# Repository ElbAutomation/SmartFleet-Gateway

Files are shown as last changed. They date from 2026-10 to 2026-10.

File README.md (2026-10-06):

# SmartFleet Gateway

Mehr zu SmartFleet: <https://smartfleetmanager.de> · Handbuch:
<https://smartfleetmanager.de/docs/>

Das SmartFleet Gateway ist ein Hutschienengerät mit 2 TE für den
Schaltschrank. Es verbindet einen Loxone Miniserver vor Ort mit dem
SmartFleet-Server des Loxone-Partners: Einrichtung über ein eigenes WLAN,
danach Kopplung und Datenaustausch über LAN oder WLAN.

*English: DIN-rail gateway (2 modules) that connects a Loxone Miniserver to a
SmartFleet server. This repository holds the firmware image and the carrier
board (Fritzing project, schematic, Gerber files, bill of materials and build
guide, in German).*

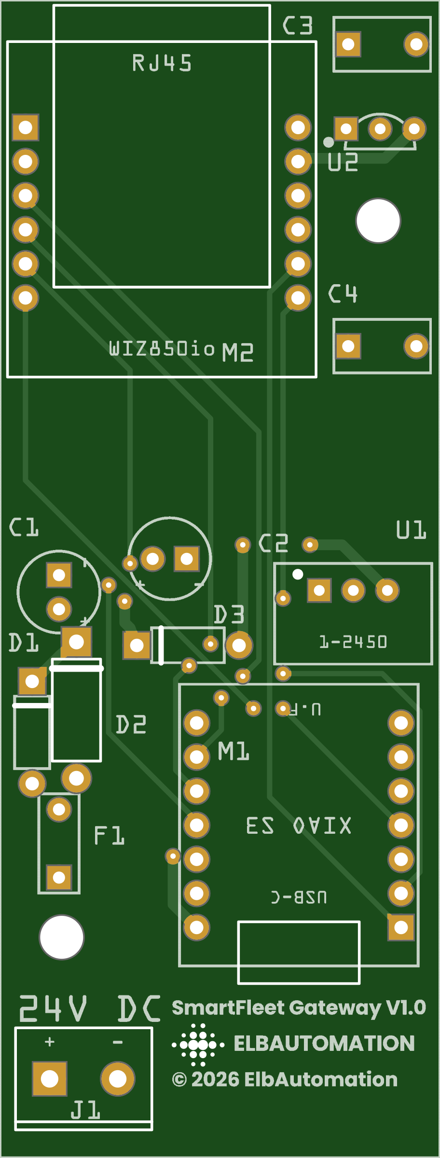
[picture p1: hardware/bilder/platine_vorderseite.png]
Trägerplatine, Vorderseite


## Inhalt

| Ordner | Was |
|---|---|
| `firmware/` | Firmware-Image für den XIAO ESP32S3 Plus auf der Trägerplatine |
| `hardware/` | Trägerplatine V1.0: Bauanleitung mit Stückliste, Fritzing-Projekt, Schaltplan, Gerber-Dateien, Bohrschablone |

## Hardware

- **ESP:** Seeed Studio XIAO ESP32S3 Plus (16 MB Flash, 8 MB PSRAM, U.FL)
- **LAN:** WIZnet WIZ850io (W5500 mit RJ45)
- **Versorgung:** 24 V DC (12–28 V), Verpolschutz, Sicherung, Überspannungsschutz
- **WLAN:** externe Stabantenne über RP-SMA-Buchse
- **Gehäuse:** Camdenboss CNMB/2, 2 TE, nach DIN 43880
- Nur Durchsteckbauteile und fertige Module, kein SMD-Löten

24 V kommen unten links an, das Netzwerkkabel oben links, die Antenne sitzt
oben rechts.

| Datei | Inhalt |
|---|---|
| [`hardware/BAUANLEITUNG.md`](hardware/BAUANLEITUNG.md) | Aufbau Schritt für Schritt, Prüfung, Gehäusebearbeitung, Stückliste |
| `hardware/stueckliste.csv` | Stückliste mit Reichelt-Links (Semikolon, UTF-8) |
| `hardware/schaltplan.pdf` | Schaltplan |
| `hardware/traegerplatine.fzz` | Fritzing-Projekt (Platine, Schaltplan, Steckbrett) |
| `hardware/traegerplatine_gerber.zip` | Fertigungsdaten für den Leiterplattenhersteller (2 Lagen, 1,6 mm) |
| `hardware/gerber/` | dieselben Gerber-Dateien einzeln |
| `hardware/bilder/` | Ansicht der Platine aus den Gerber-Dateien |
| `hardware/bohrschablone.pdf` | Schablone für Gehäuse und Klemmenabdeckung, 1:1 drucken |
| `hardware/steckbrettplan.png` | Aufbau als Prototyp auf dem Steckbrett |

**Stand:** Entwurf V1.0. Die Maße stammen aus den Datenblättern; die Anprobe
mit den echten Teilen steht noch aus. Vor dem Bestellen der Platine und vor
dem Schneiden am Gehäuse die Hinweise in der Bauanleitung beachten.

## Firmware

`firmware/smartfleet-gateway-0.1.0-xiao-esp32s3.bin` ist ein vollständiges Image (Bootloader, Partitionstabelle,
Anwendung) für den XIAO ESP32S3 Plus auf der Trägerplatine, Version 0.1.0.
Es wird ab Adresse `0x0` geschrieben.

**Im Browser** (Chrome oder Edge): <https://espressif.github.io/esptool-js/>
öffnen, *Connect* wählen, den XIAO auswählen, Adresse `0x0` und die Datei
angeben, *Program*.

**Mit esptool:**

```sh
esptool.py --chip esp32s3 write_flash 0x0 smartfleet-gateway-0.1.0-xiao-esp32s3.bin
```

Erkennt der Rechner den XIAO nicht: BOOT-Taster halten, USB-C einstecken,
loslassen. Über USB allein hat das WIZ850io keinen Strom — LAN geht erst mit
24 V an der Klemme.

Nach dem Aufspielen erscheint das Einrichtungs-WLAN `SmartFleet-XXXX`; weiter
im Handbuch. Weitere Versionen spielt das Gerät über das Netz ein; es nimmt
nur signierte Images an.

**Stand:** Die Firmware läuft auf einem ESP32-S3-Testboard. Auf der
Trägerplatine ist sie noch nicht geprüft.

## Pinbelegung XIAO ↔ WIZ850io

| Signal | XIAO | GPIO |
|---|---|---|
| CS | D10 | 9 |
| SCK | D9 | 8 |
| MOSI | D8 | 7 |
| MISO | D1 | 2 |
| RST | D0 | 1 |
| INT | D3 | 4 |
| Taster | BOOT | 0 |
| LED | — | 21 |

---

© 2026 ElbAutomation

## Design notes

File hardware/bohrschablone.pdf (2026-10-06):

## 1 Obere Klemmenabdeckung: Teil über der RJ45 abtrennen (Ansicht von vorn)

abtrennen

Stirnseite (Steckerseite)

Kante zur Stufe (Mittelteil)

Schnitt 21.9 mm ab linker Kante über die ganze Tiefe, mit Schürze RJ45 steht 3.6 mm über das Dach

2 Bohrung RP-SMA in der oberen Stufe (Ansicht von oben, Gerät mit der Front zu dir gekippt)

Kante zum oberen Klemmenraum

Front (Hals)

← RJ45-Seite | Ø 6.5 mm Mitte 28.5 mm ab linker Kante 10.8 mm ab Kante zum Klemmenraum

Prüfmaßstab 50 mm — mit 100 % drucken, nachmessen (± 0,5 mm)

Maße aus Datenblättern gerechnet (Spec 2.1), vor dem Schneiden an der Anprobe prüfen.

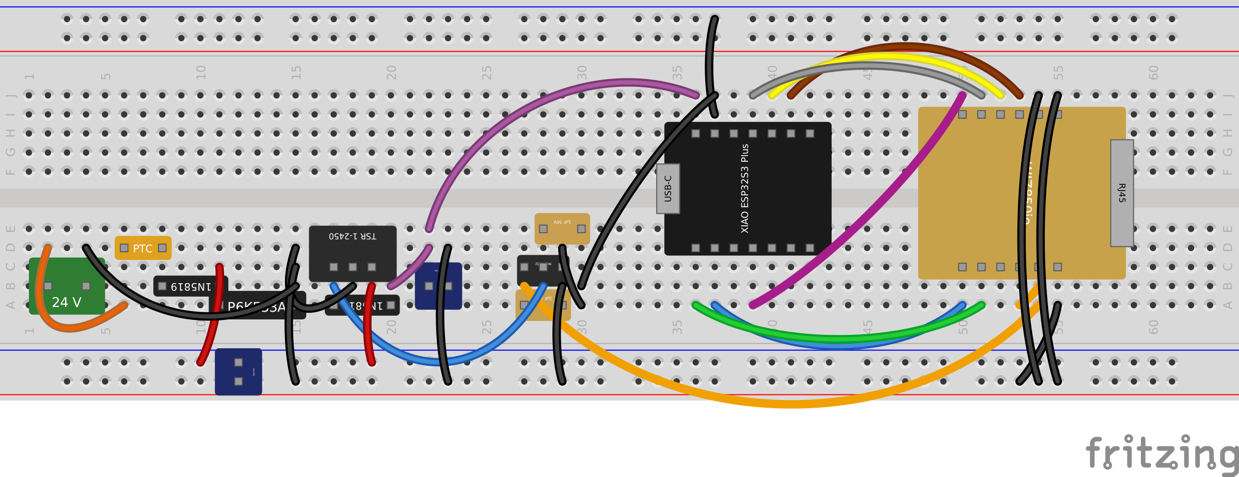
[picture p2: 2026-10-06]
hardware/steckbrettplan.png

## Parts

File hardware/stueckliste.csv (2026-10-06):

Bezeichner | Anzahl | Teil | Wert | Hersteller-Nr. | Bemerkung | Reichelt Option 1 | Reichelt Option 2
J1 | 1 | Leiterplattenklemme 2-polig, Raster 5,08 mm | Höhe 10,1 mm | Degson DG127-5.08-02P-14-00A(H) | Bauhöhe höchstens 10,5 mm (Klemmenraum) – Phoenix MKDS 1,5/2-5,08 ist mit 17,3 mm zu hoch. Ersatz: RIA AKL 101-02 (10 mm) | https://www.reichelt.de/de/de/shop/produkt/leiterplattenklemme_2_polig_rm_5_08_mm-276156 | https://www.reichelt.de/de/de/shop/produkt/anschlussklemme_2-pol_2_mm_rm_5_08-36605
F1 | 1 | Rückstellende Sicherung (PTC), radial | 0,5 A Halten / 1 A Auslösen, 60 V | Littelfuse RXEF050 | Ersatz: Bourns MF-R050 (0,5 A, 60 V) | https://www.reichelt.de/de/de/shop/produkt/rueckstellende_sicherungen_1_a-242422 | https://www.reichelt.de/de/de/shop/produkt/ptc_widerstand_750_mw_770_mohm_60_v-240126
D1 | 1 | Schottky-Diode, DO-41 | 40 V, 1 A | 1N5819 | Verpolschutz – Ring = Kathode. Ersatz: SB140 im DO-41 (nicht DO-15) | https://www.reichelt.de/de/de/shop/produkt/schottkydiode_40_v_1_a_do-41-41850 | https://www.reichelt.de/de/de/shop/produkt/schottkydiode_40_v_1_a_do-41-16024
D2 | 1 | TVS-Diode unidirektional, DO-15 | 33 V, 600 W | Littelfuse P6KE33A | Raster 10,16 mm – Ring = Kathode (an VIN). Ersatz: P6KE33A eines anderen Herstellers | https://www.reichelt.de/de/de/shop/produkt/tvs-diode_unidirectional_33_v_600_w_do-204ac_do-15-42013
D3 | 1 | Schottky-Diode, DO-41 | 40 V, 1 A | 1N5819 | vor dem 5-V-Pin des XIAO – Ring = Kathode. Ersatz: SB140 im DO-41 | https://www.reichelt.de/de/de/shop/produkt/schottkydiode_40_v_1_a_do-41-41850 | https://www.reichelt.de/de/de/shop/produkt/schottkydiode_40_v_1_a_do-41-16024
C1 | 1 | Elko radial, Ø 5 × 11 mm, RM 2,0 | 22 µF, 50 V, 105 °C | Panasonic EEUFR1H220H | stehend – TSR-Datenblatt fordert ab 32 V Eingang 22 µF / 50 V. Ersatz: jeder Elko 22 µF / 50 V, 105 °C, Ø 5 mm, RM 2,0 (z. B. Panasonic FC) | https://www.reichelt.de/de/de/shop/produkt/elko_radial_22_f_50v_105_c_low_esr-121288 | https://www.reichelt.de/de/de/shop/produkt/elko_radial_22_uf_50_v_105_c_low_esr_aec-q200-84589
C2 | 1 | Elko radial, Ø 5 × 11 mm, RM 2,0 | 47 µF, 16 V, 105 °C | Panasonic EEUFC1C470 | LIEGEND einbauen, Körper nach oben, links neben U1. Ersatz: jeder Elko 47 µF ab 16 V, 105 °C, Ø 5 × 11 mm, RM 2,0 (z. B. Panasonic NHG 47 µF / 25 V) | https://www.reichelt.de/de/de/shop/produkt/elko_radial_47_uf_16_v_105_c_low_esr_aec-q200-199902 | https://www.reichelt.de/de/de/shop/produkt/elko_radial_47_f_25_v_105_c_5_x_11_mm_rm_2_0-200353
C3 | 1 | Keramikkondensator bedrahtet, Footprint RM 5,08 | 1 µF, 50 V, X7R | KEMET C315C105K5R5TA | Ausgang U2 – oben rechts unter dem Schulterdach, beliebig herum, höchstens 9,2 mm hoch. C315 hat Raster 2,54: Beinchen auf 5,08 mm aufbiegen. Ersatz: jeder 1 µF ab 25 V, X7R oder X5R (Datenblatt MCP1702: Keramik 1–22 µF). Nicht Z5U/Y5V: verliert bei Wärme mehr als die Hälfte | https://www.reichelt.de/de/de/shop/produkt/vielschicht-kerko_1uf_63v_125_c-393649 | https://www.reichelt.de/de/de/shop/produkt/vielschicht-kerko_1_0_f_50v_125_c-206914
C4 | 1 | Keramikkondensator bedrahtet, Footprint RM 5,08 | 1 µF, 50 V, X7R | KEMET C315C105K5R5TA | Eingang U2 – rechts neben dem WIZ850io, beliebig herum. Beinchen wie bei C3 auf 5,08 mm aufbiegen. Ersatz wie C3 | https://www.reichelt.de/de/de/shop/produkt/vielschicht-kerko_1uf_63v_125_c-393649 | https://www.reichelt.de/de/de/shop/produkt/vielschicht-kerko_1_0_f_50v_125_c-206914
U1 | 1 | DC/DC-Wandler SIP3 | 5 V, 1 A, 6,5–36 V ein | Traco TSR 1-2450 | Ersatz: Traco TSR 1-2450E (7–36 V ein) – passt in denselben Footprint: Pin 1 3,26 mm von der Kante, Pinreihe 5,45 mm von der Rückseite, 10,2 mm hoch (Datenblatt TSR 1E) | https://www.reichelt.de/de/de/shop/produkt/dc_dc-wandler_tsr-1_1_w_5_v_1000_ma_sil_to-220-116850 | https://www.reichelt.de/de/de/shop/produkt/dc_dc_converter_tsr_1e_1_a_7-36_5_0_vdc_sip-3-288648
U2 | 1 | LDO-Regler TO-92 | 3,3 V, 250 mA, bis 13,2 V ein | Microchip MCP1702-3302E/TO | hängt an den 5 V von U1 – sitzt oben rechts neben der RJ45 unter dem Schulterdach – äußere Beinchen auf 2,54 mm aufbiegen. Ersatz: MCP1700-3302E/TO, gleiche Pinfolge im TO-92, Eingang höchstens 6,0 V (reicht für 5 V) | https://www.reichelt.de/de/de/shop/produkt/ldo-regler_fest_3_3_v_to-92-90114
M1 | 1 | Seeed Studio XIAO ESP32S3 Plus | 16 MB Flash, 8 MB PSRAM, U.FL | Seeed 102010671 | wird ohne Sockel direkt eingelötet. 102010671 kommt laut Seeed und DigiKey ohne angelötete Stiftleisten – dann 2 × 7 Stifte von der Stiftleiste 1 × 40 einlöten. BerryBase verkauft ihn als „pre-soldered“ (SE-102010671) | https://www.reichelt.de/de/de/shop/produkt/xiao_esp32s3_plus_dual-core_wifi_bt5_0-395757
M2 | 1 | WIZnet WIZ850io | W5500, RJ45 mit Übertrager | WIZnet WIZ850io | wird mit seinen Stiftleisten ohne Sockel flach eingelötet. Nicht bei Reichelt – auch im WIZnet-Shop: https://shop.wiznet.eu/en/wiz850io.html
 | 1 | Stiftleiste 1 × 40, gerade, RM 2,54 | — | Econ Connect SL40G1 | 2 × 7 Stifte für den XIAO, falls er ohne Leisten kommt | https://www.reichelt.de/de/de/shop/produkt/stiftleiste_1_x_40_polig_gerade_rastermass_2_54_mm-404316 | https://www.reichelt.de/de/de/shop/produkt/40pol_stiftleiste_gerade_rm_2_54-19506
 | 1 | Hutschienengehäuse 2 TE, Bausatz | 36 × 90 × 58 mm | Camdenboss CNMB/2/KIT | Gehäuse, Deckel, Klemmenabdeckungen (perforiert), Sockel, Hutschienen- und Wandclip | https://www.reichelt.de/de/de/shop/produkt/leergehaeuse_58_x_36_x_90_mm_2_te-133936
 | 1 | Antennenkabel RP-SMA-Einbaubuchse auf MHF I (U.FL-kompatibel) | 35 cm, Gewinde 10 mm | Delock 88383 | Bohrung 6,5 mm rechts in der oberen Stufe (Bohrschablone). RP-SMA, nicht SMA: die Antenne hat einen RP-SMA-Stecker | https://www.reichelt.de/de/de/shop/produkt/antennenkabel_rp-sma_buchse_mhf_i_stecker_einbau-349327
 | 1 | WLAN-Stabantenne RP-SMA-Stecker mit Kippgelenk | 2,4/5 GHz, 2 dBi @ 2,4 GHz, 143 mm | Delock 88460 | direkt auf die RP-SMA-Buchse in der oberen Stufe, zeigt nach oben; mit dem Kippgelenk zur Seite legen, wenn darüber ein Kabelkanal sitzt. Ohne Kippgelenk: Delock 88394 (89 mm) | https://www.reichelt.de/de/de/shop/produkt/wlan_antenne_rp-sma-179738 | https://www.reichelt.de/de/de/shop/produkt/wlan_antenne_rp-sma-179727
 | 1 | Leiterplatte 86,5 × 33 mm, 2 Lagen, 1,6 mm, HASL bleifrei | — | — | Fertiger nach Wahl (z. B. JLCPCB) mit traegerplatine_gerber.zip
 | 2 | Schraube für die Befestigungsdome des Gehäuses | — | — | Größe nach der Anprobe – Lochdurchmesser auf der Platine 3,2 mm

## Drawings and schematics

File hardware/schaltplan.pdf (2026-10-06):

### 22µF 50V

### P6KE33A

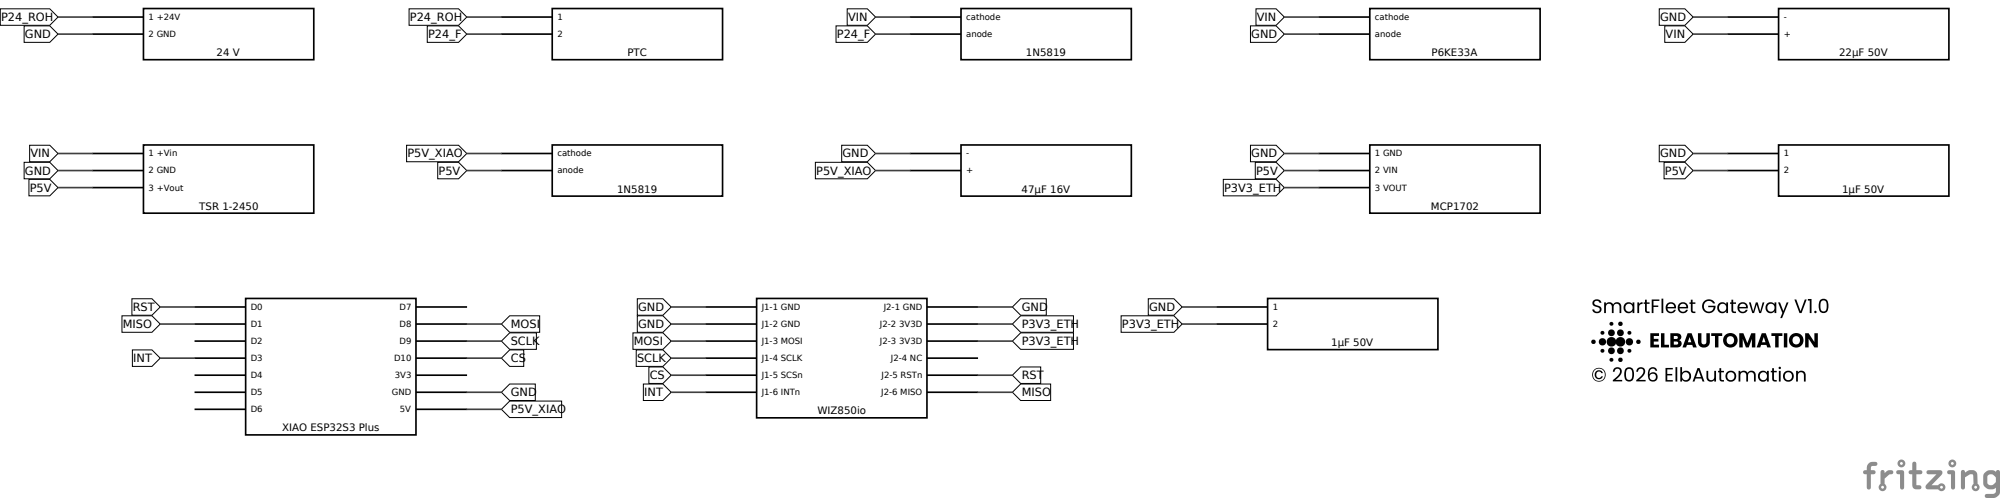
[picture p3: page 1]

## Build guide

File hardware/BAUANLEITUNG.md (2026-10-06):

# SmartFleet Gateway — Bauanleitung Trägerplatine V1.0

Ein Hutschienengerät mit 2 TE: XIAO ESP32S3 Plus und WIZ850io werden ohne
Sockel direkt auf eine Trägerplatine gelötet, die nur Durchsteckbauteile trägt.
Du lötest keine SMD-Teile.

**Stand:** Die Maße stammen aus den Datenblättern. Bevor du Platinen bestellst
oder ins Gehäuse schneidest, gehört eine Anprobe mit den echten Teilen dazu:
Passen RJ45-Stecker, Klemmenabdeckung, SMA-Buchse und USB-C-Stecker so, wie
hier beschrieben?

Lage auf der Platine: In dieser Anleitung liegt die Platine so vor dir, dass die
**Klemme unten links** und das **WIZ850io oben links** liegt; der Schriftzug
„SmartFleet Gateway V1.0“ steht unten rechts neben der Klemme.
„Links“ ist die Seite der Klemme.

## 1. Teile prüfen

Die Stückliste steht am Ende dieser Anleitung und als `stueckliste.csv`, je
Teil mit Reichelt-Link und, wo es eins gibt, einem Ersatzteil, falls das erste
nicht lieferbar ist. Leg die Teile nach
Bezeichner bereit (C1 … U2). Die Platine bestellst du mit
`traegerplatine_gerber.zip` bei einem Leiterplattenfertiger (2 Lagen, 1,6 mm,
HASL bleifrei).

Du brauchst: Lötkolben, Lötzinn, Seitenschneider, Multimeter, Labornetzteil oder
24-V-Netzteil, Bohrer 6,5 mm, kleine Feile oder Cuttermesser.

## 2. Löten — niedrige Teile zuerst

| Schritt | Teil | Worauf achten |
|---|---|---|
| 1 | D1, D2 (links, senkrecht) | **Ring nach oben.** D1 ist die 1N5819, D2 die dickere P6KE33A |
| 2 | D3 (über dem XIAO, links neben U1, waagerecht) | 1N5819, **Ring nach links** |
| 3 | F1 | PTC, beliebig herum |
| 4 | C2 (über D3) | **Liegend:** Plusbein links, Minusbein rechts, Beine 90° biegen, Körper flach nach **oben** auf die Platine legen |
| 5 | U2 (oben rechts, neben der RJ45) | MCP1702 im TO-92: die beiden **äußeren Beinchen auf 2,54 mm aufbiegen**. **Flache Seite nach unten**, wie die gerade Linie im Bestückungsdruck. Höchstens 8 mm hoch, er sitzt unter dem Schulterdach |
| 6 | C3 (oben rechts, über U2), C4 (rechts neben dem WIZ850io) | Keramik 1 µF, beliebig herum, stehend bis auf die Platine. Hat das Teil Raster 2,54 (KEMET C315), die Beinchen auf 5,08 mm aufbiegen |
| 7 | C1 (links) | Stehend, **Minusstreifen nach oben** |
| 8 | U1 (Mitte, über dem XIAO) | Traco TSR 1-2450. Der **Punkt am Wandler** (Pin 1) gehört zum **Punkt im Bestückungsdruck**; Pin 1 liegt links |
| 9 | J1 (unten links) | Klemme mit der **Leitereinführung zum unteren Platinenrand** |

Die beiden Module kommen erst nach der Prüfung in Abschnitt 3 dran.

## 3. Prüfung vor dem Einlöten der Module

Die Module sind noch **nicht** eingelötet. Gemessen wird an ihren Lötaugen.

1. 24 V an J1 anlegen (+ links, − rechts).
2. 5-V-Zweig messen: linke XIAO-Reihe, **unterstes Lötauge** (5V) gegen das
   darüber (GND). Erwartet: **4,6–5,0 V**.
3. 3,3-V-Zweig messen: rechte WIZ-Reihe, **zweites und drittes Lötauge von
   oben** (3V3) gegen das oberste (GND). Erwartet: **3,20–3,40 V**.
4. Verpolung probieren: 24 V vertauscht anlegen. Das Netzteil zeigt unter
   1 mA, nichts wird warm. Danach wieder richtig herum anschließen, die Werte
   aus 2 und 3 sind unverändert.

Stimmt ein Wert nicht, lötest du **kein** Modul ein, bevor der Fehler gefunden ist.

## 4. Module einlöten

Beide Module liegen **flach** auf: Der Kunststoffsteg ihrer Stiftleisten sitzt
auf der Trägerplatine.

- **XIAO:** **USB-C nach unten** zur Klemmenseite, wie im Bestückungsdruck
  „USB-C“. Kommt er ohne Stiftleisten: zwei 7-polige Stücke von der
  Stiftleiste 1 × 40 abtrennen, mit dem langen Ende in die Trägerplatine
  stecken, XIAO aufsetzen, erst oben am XIAO löten, dann unten.
- **WIZ850io:** **RJ45 nach oben**, Öffnung zur oberen Platinenkante, wie im
  Bestückungsdruck „RJ45“.

Beide Module passen mechanisch auch verdreht auf die Platine. Verdreht liegen
5 V bzw. 3,3 V an den falschen Pins, und eingelötet lässt sich das kaum noch
korrigieren. Prüf die Lage deshalb **vor dem ersten Lötpunkt** zweimal. Löte
zuerst je einen Eckpin, prüf, ob das Modul flach aufliegt, dann den Rest.

## 5. Gehäuse bearbeiten

1. `bohrschablone.pdf` mit **100 %** drucken. Den Prüfmaßstab nachmessen: 50 mm
   ± 0,5 mm.
2. **Obere Klemmenabdeckung:** links den Teil über der RJ45 nach Schablone 1
   abtrennen, über die ganze Tiefe. Die RJ45 steht dort etwas über das
   Schulterdach, der Stecker kommt von oben durch die Stirnseite.
3. **RP-SMA-Bohrung** 6,5 mm rechts in der oberen Stufe des Gehäuses (zwischen
   oberem Klemmenraum und Front) nach Schablone 2.
4. Einbaubuchse des Antennenkabels (Delock 88383) mit Mutter und Sicherungsring
   befestigen.

## 6. Antenne

Den MHF-I-Stecker des Kabels **senkrecht** auf die U.FL-Buchse des XIAO
drücken, bis er einrastet. Nicht schräg ansetzen, die Buchse ist klein.
Die Stabantenne (Delock 88460) wird direkt auf die RP-SMA-Buchse geschraubt
und zeigt nach oben, neben dem Netzwerkkabel. Sitzt darüber ein Kabelkanal,
legst du sie mit dem Kippgelenk zur Seite.

## 7. Firmware aufspielen (Erstflash)

Der XIAO ist eingelötet; seine USB-C-Buchse zeigt nach unten an die Stufe zum
unteren Klemmenraum. Rechts neben der Klemme ist der Weg frei: Ein gerader
USB-C-Stecker passt, solange die Platine noch nicht im Gehäuse liegt oder die
untere Klemmenabdeckung ab ist.

Das Firmware-Image und die Anleitung zum Aufspielen liegen im Ordner
`firmware/` des Repositories SmartFleet-Gateway.

**Über USB allein hat das WIZ850io keinen Strom.** LAN geht nur mit 24 V an J1.
USB und 24 V gleichzeitig sind erlaubt: D3 verhindert, dass Strom in den
USB-Anschluss des Rechners zurückfließt.

Spätere Updates kommen über das Netz.

## 8. Einbau und Anschluss

1. Platine in die untere Platinenebene des Gehäuses einlegen und an den beiden
   Befestigungsdomen festschrauben (Schraubengröße nach der Anprobe).
2. Deckel aufsetzen, Gehäuse auf die Hutschiene.
3. **24 V** (12–28 V) an die Klemme, **Netzwerkkabel** von oben in die RJ45.
4. Das Einrichtungs-WLAN `SmartFleet-XXXX` erscheint. Weiter mit der
   Einrichtung, siehe Handbuch zum SmartFleet Gateway.

## Prototyp auf dem Steckbrett

Zum Ausprobieren vor der Platine: `steckbrettplan.png` zeigt den kompletten
Aufbau auf einem Breadboard mit 830 Kontakten (63 Spalten, Reihen A–J). Die
Projektdatei `traegerplatine.fzz` enthält dieselbe Ansicht in Fritzing.

- **Schienen:** unten außen GND, unten innen VIN (nach der Verpoldiode), oben
  außen GND; oben innen bleibt frei.
- XIAO (USB-C links) und WIZ850io (RJ45 rechts) überbrücken jeweils den
  Mittelsteg.
- C1 steckt direkt zwischen den beiden unteren Schienen. U2 (MCP1702) sitzt
  mit C3 und C4 in den Spalten 27–30.
- **24 V am einfachsten mit zwei Drahtbrücken zuführen** (+ in Spalte 2,
  − in Spalte 4) statt über die Klemme J1. Ob deren Stifte in die Kontakte
  deines Steckbretts passen, hängt vom Brett ab.

## Stückliste

| Bez. | Anz. | Teil | Wert | Hersteller-Nr. | Bemerkung | Reichelt |
|---|---|---|---|---|---|---|
| J1 | 1 | Leiterplattenklemme 2-polig, Raster 5,08 mm | Höhe 10,1 mm | Degson DG127-5.08-02P-14-00A(H) | Bauhöhe höchstens 10,5 mm (Klemmenraum) – Phoenix MKDS 1,5/2-5,08 ist mit 17,3 mm zu hoch. Ersatz: RIA AKL 101-02 (10 mm) | [DG127-5.08-02P-14-00A(H)](https://www.reichelt.de/de/de/shop/produkt/leiterplattenklemme_2_polig_rm_5_08_mm-276156) · [31101102](https://www.reichelt.de/de/de/shop/produkt/anschlussklemme_2-pol_2_mm_rm_5_08-36605) |
| F1 | 1 | Rückstellende Sicherung (PTC), radial | 0,5 A Halten / 1 A Auslösen, 60 V | Littelfuse RXEF050 | Ersatz: Bourns MF-R050 (0,5 A, 60 V) | [RXEF050](https://www.reichelt.de/de/de/shop/produkt/rueckstellende_sicherungen_1_a-242422) · [MF-R050](https://www.reichelt.de/de/de/shop/produkt/ptc_widerstand_750_mw_770_mohm_60_v-240126) |
| D1 | 1 | Schottky-Diode, DO-41 | 40 V, 1 A | 1N5819 | Verpolschutz – Ring = Kathode. Ersatz: SB140 im DO-41 (nicht DO-15) | [1N5819](https://www.reichelt.de/de/de/shop/produkt/schottkydiode_40_v_1_a_do-41-41850) · [SB140](https://www.reichelt.de/de/de/shop/produkt/schottkydiode_40_v_1_a_do-41-16024) |
| D2 | 1 | TVS-Diode unidirektional, DO-15 | 33 V, 600 W | Littelfuse P6KE33A | Raster 10,16 mm – Ring = Kathode (an VIN). Ersatz: P6KE33A eines anderen Herstellers | [P6KE33A](https://www.reichelt.de/de/de/shop/produkt/tvs-diode_unidirectional_33_v_600_w_do-204ac_do-15-42013) |
| D3 | 1 | Schottky-Diode, DO-41 | 40 V, 1 A | 1N5819 | vor dem 5-V-Pin des XIAO – Ring = Kathode. Ersatz: SB140 im DO-41 | [1N5819](https://www.reichelt.de/de/de/shop/produkt/schottkydiode_40_v_1_a_do-41-41850) · [SB140](https://www.reichelt.de/de/de/shop/produkt/schottkydiode_40_v_1_a_do-41-16024) |
| C1 | 1 | Elko radial, Ø 5 × 11 mm, RM 2,0 | 22 µF, 50 V, 105 °C | Panasonic EEUFR1H220H | stehend – TSR-Datenblatt fordert ab 32 V Eingang 22 µF / 50 V. Ersatz: jeder Elko 22 µF / 50 V, 105 °C, Ø 5 mm, RM 2,0 (z. B. Panasonic FC) | [EEUFR1H220H](https://www.reichelt.de/de/de/shop/produkt/elko_radial_22_f_50v_105_c_low_esr-121288) · [EEUFC1H220H](https://www.reichelt.de/de/de/shop/produkt/elko_radial_22_uf_50_v_105_c_low_esr_aec-q200-84589) |
| C2 | 1 | Elko radial, Ø 5 × 11 mm, RM 2,0 | 47 µF, 16 V, 105 °C | Panasonic EEUFC1C470 | LIEGEND einbauen, Körper nach oben, links neben U1. Ersatz: jeder Elko 47 µF ab 16 V, 105 °C, Ø 5 × 11 mm, RM 2,0 (z. B. Panasonic NHG 47 µF / 25 V) | [EEUFC1C470](https://www.reichelt.de/de/de/shop/produkt/elko_radial_47_uf_16_v_105_c_low_esr_aec-q200-199902) · [ECA1EHG470](https://www.reichelt.de/de/de/shop/produkt/elko_radial_47_f_25_v_105_c_5_x_11_mm_rm_2_0-200353) |
| C3 | 1 | Keramikkondensator bedrahtet, Footprint RM 5,08 | 1 µF, 50 V, X7R | KEMET C315C105K5R5TA | Ausgang U2 – oben rechts unter dem Schulterdach, beliebig herum, höchstens 9,2 mm hoch. C315 hat Raster 2,54: Beinchen auf 5,08 mm aufbiegen. Ersatz: jeder 1 µF ab 25 V, X7R oder X5R (Datenblatt MCP1702: Keramik 1–22 µF). Nicht Z5U/Y5V: verliert bei Wärme mehr als die Hälfte | [C315C105K5R5TA](https://www.reichelt.de/de/de/shop/produkt/vielschicht-kerko_1uf_63v_125_c-393649) · [CK06BX105K](https://www.reichelt.de/de/de/shop/produkt/vielschicht-kerko_1_0_f_50v_125_c-206914) |
| C4 | 1 | Keramikkondensator bedrahtet, Footprint RM 5,08 | 1 µF, 50 V, X7R | KEMET C315C105K5R5TA | Eingang U2 – rechts neben dem WIZ850io, beliebig herum. Beinchen wie bei C3 auf 5,08 mm aufbiegen. Ersatz wie C3 | [C315C105K5R5TA](https://www.reichelt.de/de/de/shop/produkt/vielschicht-kerko_1uf_63v_125_c-393649) · [CK06BX105K](https://www.reichelt.de/de/de/shop/produkt/vielschicht-kerko_1_0_f_50v_125_c-206914) |
| U1 | 1 | DC/DC-Wandler SIP3 | 5 V, 1 A, 6,5–36 V ein | Traco TSR 1-2450 | Ersatz: Traco TSR 1-2450E (7–36 V ein) – passt in denselben Footprint: Pin 1 3,26 mm von der Kante, Pinreihe 5,45 mm von der Rückseite, 10,2 mm hoch (Datenblatt TSR 1E) | [TSR 1-2450](https://www.reichelt.de/de/de/shop/produkt/dc_dc-wandler_tsr-1_1_w_5_v_1000_ma_sil_to-220-116850) · [TSR 1-2450E](https://www.reichelt.de/de/de/shop/produkt/dc_dc_converter_tsr_1e_1_a_7-36_5_0_vdc_sip-3-288648) |
| U2 | 1 | LDO-Regler TO-92 | 3,3 V, 250 mA, bis 13,2 V ein | Microchip MCP1702-3302E/TO | hängt an den 5 V von U1 – sitzt oben rechts neben der RJ45 unter dem Schulterdach – äußere Beinchen auf 2,54 mm aufbiegen. Ersatz: MCP1700-3302E/TO, gleiche Pinfolge im TO-92, Eingang höchstens 6,0 V (reicht für 5 V) | [MCP1702-3302E/TO](https://www.reichelt.de/de/de/shop/produkt/ldo-regler_fest_3_3_v_to-92-90114) |
| M1 | 1 | Seeed Studio XIAO ESP32S3 Plus | 16 MB Flash, 8 MB PSRAM, U.FL | Seeed 102010671 | wird ohne Sockel direkt eingelötet. 102010671 kommt laut Seeed und DigiKey ohne angelötete Stiftleisten – dann 2 × 7 Stifte von der Stiftleiste 1 × 40 einlöten. BerryBase verkauft ihn als „pre-soldered“ (SE-102010671) | [102010671](https://www.reichelt.de/de/de/shop/produkt/xiao_esp32s3_plus_dual-core_wifi_bt5_0-395757) |
| M2 | 1 | WIZnet WIZ850io | W5500, RJ45 mit Übertrager | WIZnet WIZ850io | wird mit seinen Stiftleisten ohne Sockel flach eingelötet. Nicht bei Reichelt – auch im WIZnet-Shop: https://shop.wiznet.eu/en/wiz850io.html | — |
|  | 1 | Stiftleiste 1 × 40, gerade, RM 2,54 | — | Econ Connect SL40G1 | 2 × 7 Stifte für den XIAO, falls er ohne Leisten kommt | [SL40G1](https://www.reichelt.de/de/de/shop/produkt/stiftleiste_1_x_40_polig_gerade_rastermass_2_54_mm-404316) · [SL 1X40G 2,54](https://www.reichelt.de/de/de/shop/produkt/40pol_stiftleiste_gerade_rm_2_54-19506) |
|  | 1 | Hutschienengehäuse 2 TE, Bausatz | 36 × 90 × 58 mm | Camdenboss CNMB/2/KIT | Gehäuse, Deckel, Klemmenabdeckungen (perforiert), Sockel, Hutschienen- und Wandclip | [CNMB/2/KIT](https://www.reichelt.de/de/de/shop/produkt/leergehaeuse_58_x_36_x_90_mm_2_te-133936) |
|  | 1 | Antennenkabel RP-SMA-Einbaubuchse auf MHF I (U.FL-kompatibel) | 35 cm, Gewinde 10 mm | Delock 88383 | Bohrung 6,5 mm rechts in der oberen Stufe (Bohrschablone). RP-SMA, nicht SMA: die Antenne hat einen RP-SMA-Stecker | [88383](https://www.reichelt.de/de/de/shop/produkt/antennenkabel_rp-sma_buchse_mhf_i_stecker_einbau-349327) |
|  | 1 | WLAN-Stabantenne RP-SMA-Stecker mit Kippgelenk | 2,4/5 GHz, 2 dBi @ 2,4 GHz, 143 mm | Delock 88460 | direkt auf die RP-SMA-Buchse in der oberen Stufe, zeigt nach oben; mit dem Kippgelenk zur Seite legen, wenn darüber ein Kabelkanal sitzt. Ohne Kippgelenk: Delock 88394 (89 mm) | [88460](https://www.reichelt.de/de/de/shop/produkt/wlan_antenne_rp-sma-179738) · [88394](https://www.reichelt.de/de/de/shop/produkt/wlan_antenne_rp-sma-179727) |
|  | 1 | Leiterplatte 86,5 × 33 mm, 2 Lagen, 1,6 mm, HASL bleifrei | — | — | Fertiger nach Wahl (z. B. JLCPCB) mit traegerplatine_gerber.zip | — |
|  | 2 | Schraube für die Befestigungsdome des Gehäuses | — | — | Größe nach der Anprobe – Lochdurchmesser auf der Platine 3,2 mm | — |

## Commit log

2026-10-06 SmartFleet Gateway: Firmware 0.1.0 und Traegerplatine V1.0
    Firmware-Image fuer den XIAO ESP32S3 Plus auf der Traegerplatine,
    Fritzing-Projekt, Schaltplan, Gerber-Dateien mit Ansicht der Vorderseite,
    Stueckliste, Bohrschablone und Bauanleitung.
    [stueckliste.csv, traegerplatine.fzz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]
2026-10-06 Traegerplatine: Bauteilbezeichner im Bestueckungsdruck, Schaltplan mit schlankem Schriftfeld
    [traegerplatine.fzz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]
2026-10-17 Firmware 1.0.0
    Erste Version mit Updates ueber das Netz: das Gateway holt signierte
    Versionen von smartfleetmanager.de/downloads/gateway/ und nimmt nur
    Images an, die mit dem SmartFleet-Release-Schluessel signiert sind.
    Dazu der Aufbau nur mit XIAO und WIZ850io ueber USB (steckbrett_usb).
